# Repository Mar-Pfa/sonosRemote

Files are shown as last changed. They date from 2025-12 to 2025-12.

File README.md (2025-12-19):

# sonosRemote
simple hardware remote control for my sonos speaker

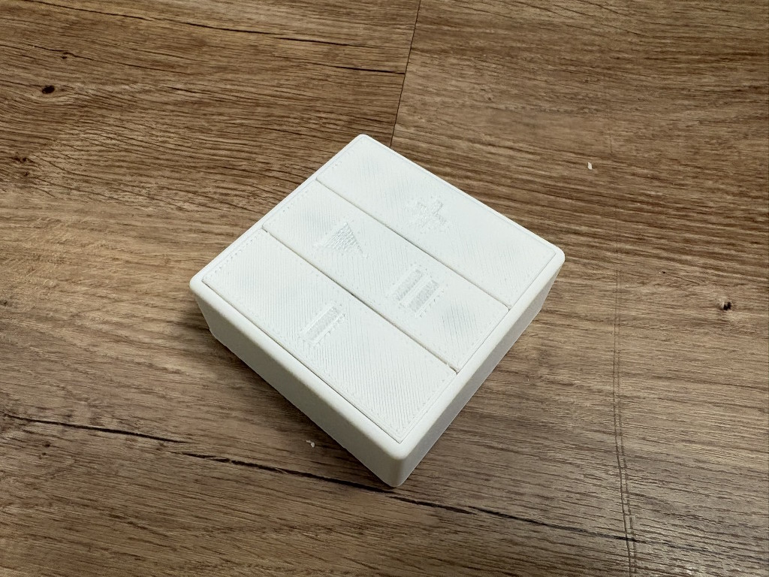
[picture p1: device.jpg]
device

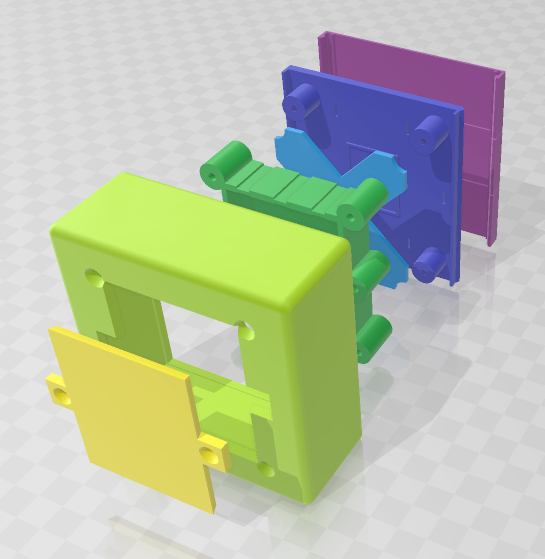
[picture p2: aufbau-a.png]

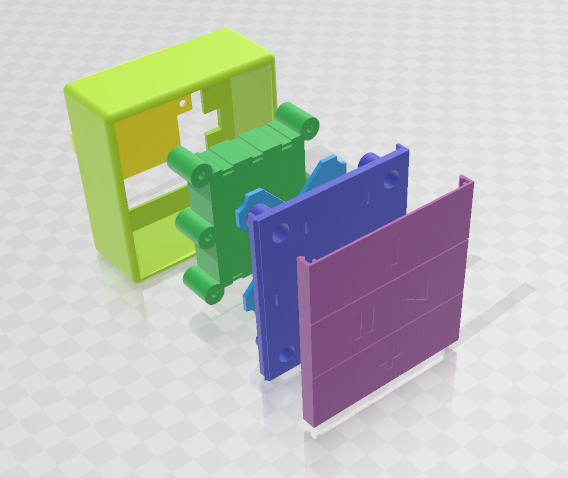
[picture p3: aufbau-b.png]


# ESP32 ⚙️ Funktionen

- **3 Taster** für Lauter, Play/Pause, Leiser
- **Deep Sleep** im Ruhezustand (<0.1 mA)
- **Wake-up per GPIO** (Tasterdruck auf Lauter)
- **60 Sekunden Aktiv-Zeit** vor erneutem Schlaf
- **WLAN-Verbindung** zu Sonos-Lautsprecher
- **mDNS-Unterstützung** (z. B. `http://sonosremote.local`)
- **Arduino OTA** für Over-the-Air-Updates

---

## 💡 LED Statusanzeige

Die eingebaute LED zeigt verschiedene Gerätezustände an:

| Zustand | LED-Muster | Bedeutung |
|---|---|---|
| Startphase | 0,1s an / 0,15s aus | WLAN-Verbindungsaufbau läuft |
| Tastendruck | 0,5s an | Bestätigung der Tasteneingabe |
| Aktiv-Wartemodus | 0,1s an / 0,4s aus | Gerät ist aktiv, wartet auf Befehle/OTA |
| Deep Sleep | LED aus | Gerät im Stromsparmodus |

Die LED-Zeiten können über Konstanten in `sonos.ino` angepasst werden:
```cpp
#define LED_STARTUP_ON_MS   100  // LED an während Start
#define LED_STARTUP_OFF_MS  150  // LED aus während Start
#define LED_FEEDBACK_MS     500  // Tastendruckbestätigung
#define LED_IDLE_ON_MS      100  // LED an im Wartezustand
#define LED_IDLE_OFF_MS     400  // LED aus im Wartezustand
```

---

## 🔧 Hardwareit Deep Sleep, OTA & mDNS

## 🎯 Ziel

Ein ESP32-Sketch, der sich per WLAN verbindet, drei Taster ausliest und bei Tastendruck einen definierten Sonos-Lautsprecher steuert.  
Das System ist stromsparend durch Deep Sleep, unterstützt mDNS und Arduino OTA.

---

## 🔧 Benötigte Komponenten

| Komponente | Bild
|---|--- |
| ESP32C3 Supermini |
| Akku - 3× 1.2 V NiMH (3.6 V gesamt) |
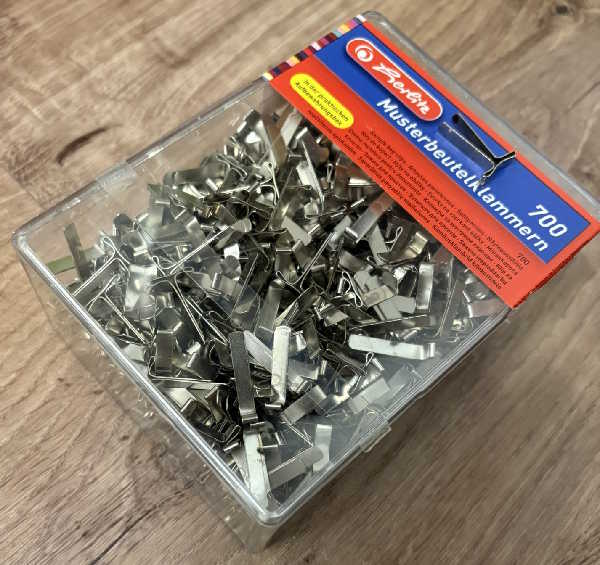
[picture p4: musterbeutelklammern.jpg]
| Musterbeutelklammern für die elektrischen Kontakte an der Batterie | 
| Ein paar kleine Kabel |
| etwas Alufolie als Kontaktschalter auf der Unterseite der Knöpfe |
| Sonos Lautsprecher - WLAN-fähig, im gleichen Netz |

---

## 🧱 Gehäuse & 3D-Dateien

Im Ordner `3d/` befinden sich **alle nötigen 3D-Dateien** für das Gehäuse:

- Die Datei `remote.3mf` enthält **alle Komponenten** zusammen; **alle "weißen" Objekte müssen subtrahiert werden**, bevor die Teile zusammengesetzt bzw. gedruckt werden.
- Zusätzlich gibt es die Einzelteile als `*.stl`-Dateien (z. B. `Baseplate.3mf`, `BatteryHolder.3mf`, `Buttons.3mf`).

> **Tipp:** Öffne `remote.3mf` in deinem 3D-Programm, führe die Subtraktion der weißen Objekte aus und exportiere bei Bedarf einzelne STL-Dateien für den Druck. 🔧

---

## ⚠️ WLAN-Einstellungen

Die **WLAN-Einstellungen (SSID, Passwort, evtl. statische IP)** befinden sich in `sonos/settings.h`. **Ändere dort die Werte vor dem ersten Flashen des Geräts.**

---

## 💻 Bibliotheken

- `WiFi.h`
- `SonosUPnP.h` ([javos65/Sonos-ESP32](https://github.com/javos65/Sonos-ESP32))
- `ArduinoOTA.h`
- `ESPmDNS.h`

---

## 🔋 Energieverbrauch & Laufzeit

| Zustand | Strom | Dauer/Tag | Verbrauch |
|---|---|---|---|
| Deep Sleep | 0.08 mA | 23 h 50 min | 2 mAh |
| Aktiv (WLAN, OTA-fähig) | 90 mA | 10 s × 100 | 25 mAh |
| **Gesamt** | | | **≈ 27 mAh/Tag** |

Mit 1200 mAh Akku: **ca. 44 Tage Laufzeit** bei 100 Betätigungen/Tag  
→ bei geringerer Nutzung: **mehrere Monate Laufzeit**.

---

## 🧠 Ablauf

1. **Deep Sleep:** ESP32 schläft mit nur RTC aktiv (0.05–0.1 mA).  
2. **Tastendruck:** weckt ESP32 (Wake-on-GPIO).  
3. **WLAN-Verbindung:** Aufbau (~1–2 s).  
4. **Sonos-Befehl:** Lauter, Leiser oder Play/Pause.  
5. **OTA/mDNS aktiv:** 60 s lang erreichbar.  
6. **Automatisch zurück in Deep Sleep.**

---

## 💡 Tipps

- OTA funktioniert **nur während der Aktivzeit (60 s)**.  
  → Taste drücken, dann OTA-Upload starten.  
- mDNS erlaubt Zugriff via `http://sonosremote.local` oder Ping.  
- Aktivzeit anpassen über:
  ```cpp
  const uint64_t AUTO_SLEEP_AFTER_MS = 60000; // 10 Sekunden
  ```

---

## ✅ Vorteile

- Extrem stromsparend
- schnelle Reaktion (<2 s)
- OTA & mDNS ohne Kabel
- Ideal für Akkubetrieb

---

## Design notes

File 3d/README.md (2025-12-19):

# Infos zum Druck

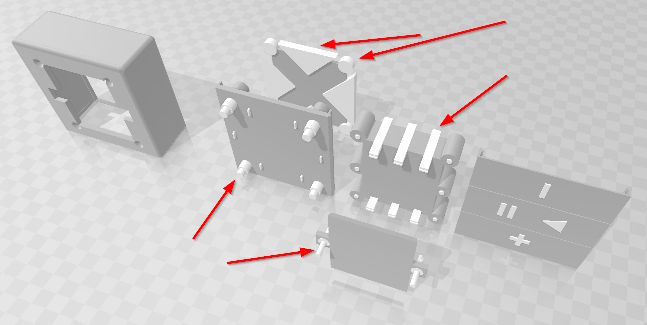
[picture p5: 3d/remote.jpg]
remote


In diesem Ordner findest du alle 3D-Dateien für das Gehäuse:

- **`remote.3mf`** — enthält alle Komponenten; das Modell wurde mit Microsoft 3D Builder erstellt. **Wichtiger Hinweis:** Alle **"weißen" Objekte** müssen vor dem Export bzw. Druck **subtrahiert** (Boolean/Difference) werden, da sie als Platzhalter/Schnitt-Objekte dienen.
- **Einzelteile / STLs** — zusätzlich liegen die Einzeldateien als STL-Exporte vor (z. B. `Baseplate.stl`, `BatteryDeckel.stl`, `Buttons.stl`, `Abdeckplatte.stl`) und können verwendet werden, wenn keine weiteren Anpassungen nötig sind.

### 3D-Druck

Für meine Fernbedienung habe ich alle Teile mit folgenden Settings gedruckt: 
- Schichthöhe: **0.2 mm** 
- Infill: **25 %**

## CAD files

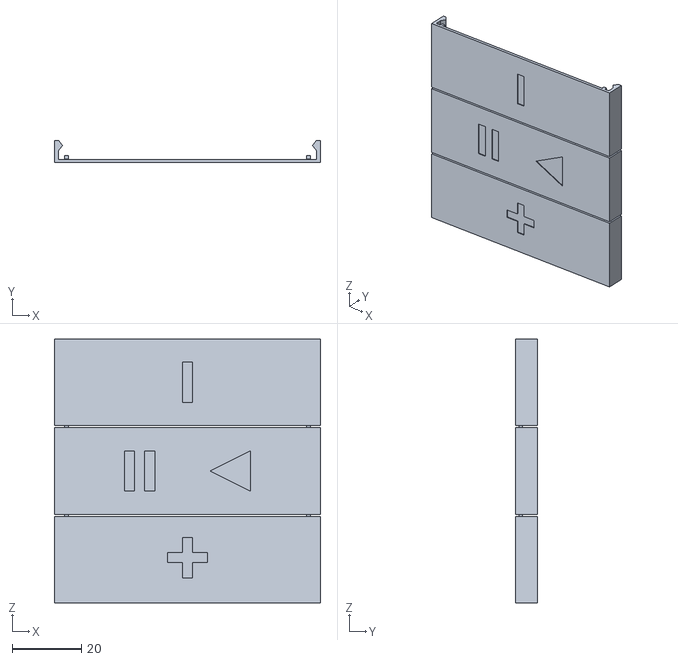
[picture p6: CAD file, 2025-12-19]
3d/Buttons.stl
77.0 x 6.50 x 76.4

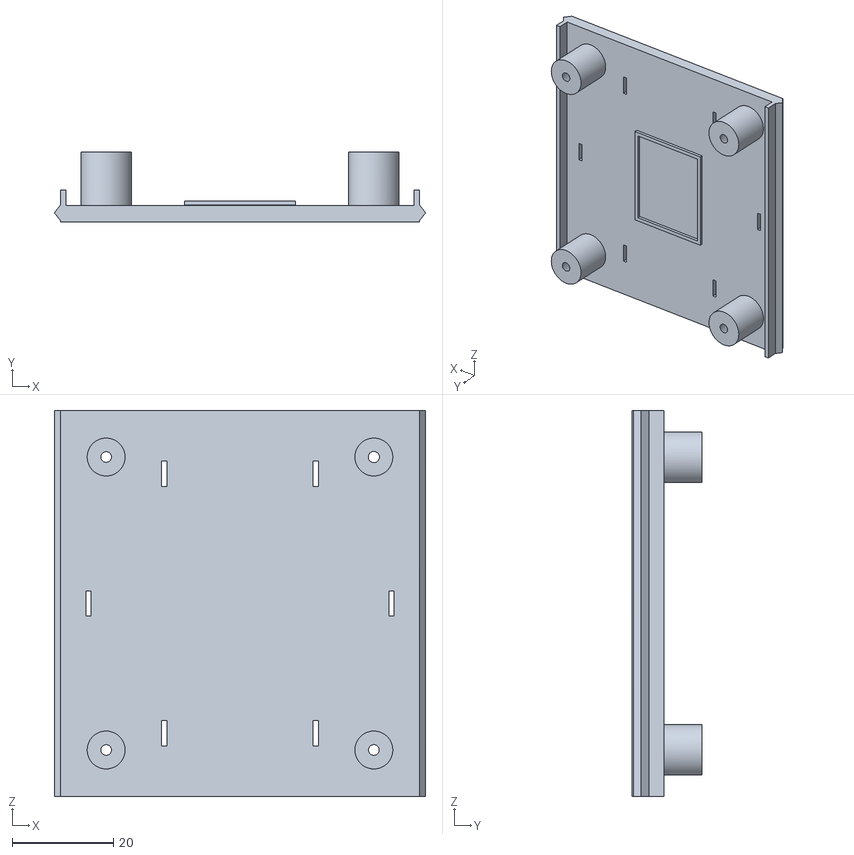
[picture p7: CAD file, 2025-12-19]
3d/Baseplate.stl
73.5 x 13.8 x 76.4

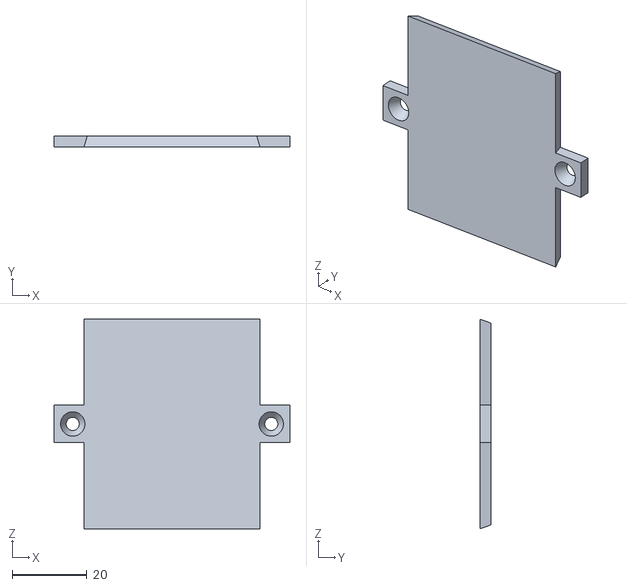
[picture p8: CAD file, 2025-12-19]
3d/BatterieDeckel.stl
63.0 x 3.00 x 56.0

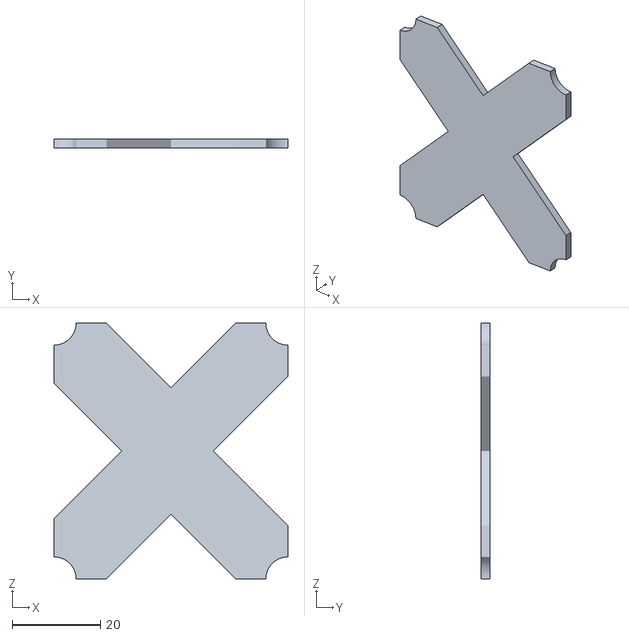
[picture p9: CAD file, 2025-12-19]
3d/Abdeckplatte.stl
53.0 x 2.00 x 58.0

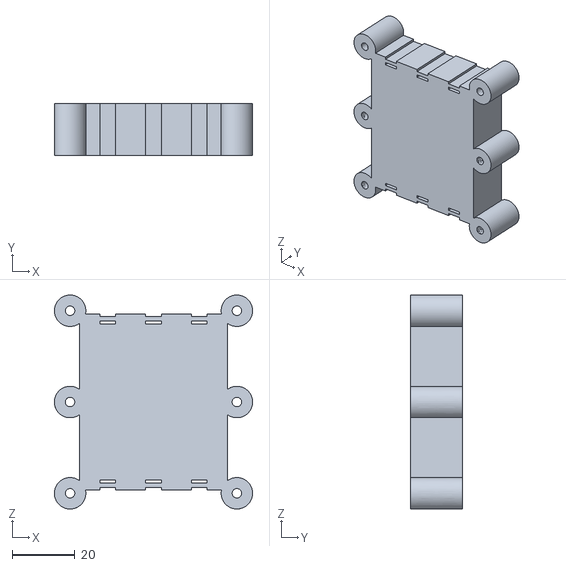
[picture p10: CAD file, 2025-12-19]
3d/batterieGehäuse.stl
63.0 x 16.5 x 68.0

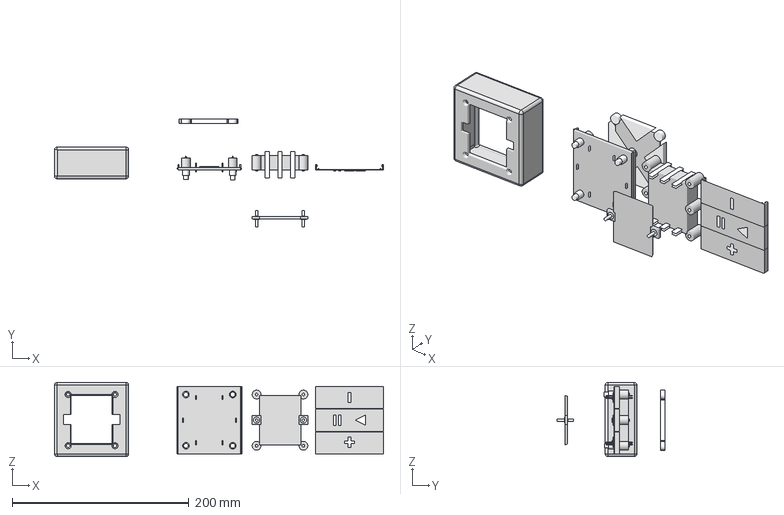
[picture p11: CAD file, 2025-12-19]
3d/remote.3mf
372.5 x 122.5 x 84.0 mm

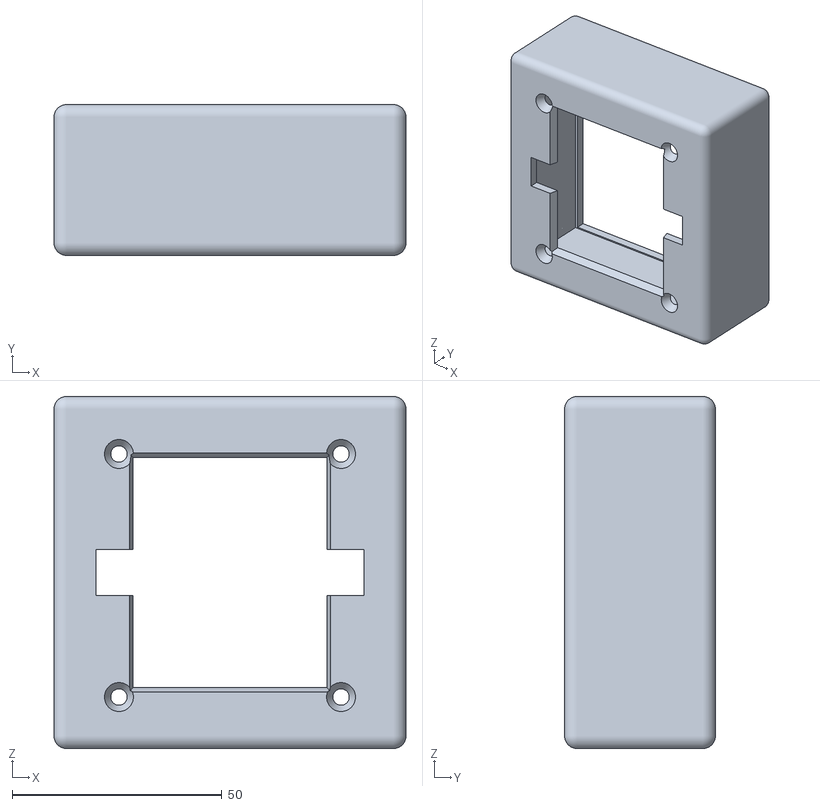
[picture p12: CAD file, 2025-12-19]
3d/Gehäuse.stl
84.0 x 36.0 x 84.0

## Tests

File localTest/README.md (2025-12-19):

# Sonos Web Remote

Eine einfache Weboberfläche zur Steuerung eines Sonos-Lautsprechers.

## Installation

1. Node.js installieren (v14 oder höher)
2. In das `web`-Verzeichnis wechseln:
   ```bash
   cd web
   ```
3. Dependencies installieren:
   ```bash
   npm install
   ```
4. Server starten:
   ```bash
   npm start
   ```
5. Im Browser öffnen: http://localhost:3000

## Funktionen

- Play/Pause Toggle
- Lautstärke erhöhen (+5)
- Lautstärke verringern (-5)

## Technische Details

- Express.js Server
- Direkter UPnP/SOAP-Zugriff auf Sonos
- Responsives Web-Interface
- Fehlerbehandlung mit visueller Rückmeldung

## Konfiguration

Die Sonos-IP-Adresse kann in `server.js` angepasst werden:

```js
const SONOS_IP = '192.168.2.228';  // IP des Sonos-Lautsprechers
```

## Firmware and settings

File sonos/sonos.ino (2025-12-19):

#include <WiFi.h>
#include <ArduinoOTA.h>
#include <ESPmDNS.h>
#include "esp_sleep.h"
#include "SonosUPnP.h"
#include "settings.h"

// ===== WLAN & Sonos =====
IPAddress SONOS_IP(192,168,2,228);
WiFiClient wifiClient;
SonosUPnP sonos(wifiClient);

// ===== mDNS & OTA =====
const char* HOSTNAME = "sonosremote";

// ===== Button Pins =====
#define BTN_DOWN 3
#define BTN_PLAY 4
#define BTN_UP   5

// ===== LED =====
#define LED_PIN 2 // onboard LED (change if different)

// LED state/timers
unsigned long ledFeedbackUntil = 0; // millis until which feedback LED stays on
unsigned long ledBlinkNext = 0;     // next toggle time for idle blink
bool ledBlinkOn = false;

// ===== LED Timing Constants (ms) =====
#define LED_STARTUP_ON_MS   100
#define LED_STARTUP_OFF_MS  150
#define LED_FEEDBACK_MS     500
#define LED_IDLE_ON_MS      100
#define LED_IDLE_OFF_MS     400
#define WIFI_CONNECT_TIMEOUT_MS 7000

// ===== Sleep Settings =====
const uint64_t AUTO_SLEEP_AFTER_MS = 60000;   // 30 Sekunden aktiv
RTC_DATA_ATTR int wakePin = -1;
unsigned long lastAction = 0;
bool actionDone = false;

// ===== Lautstärke Schrittweite =====
const int VOL_STEP = 5;

void setupButtons() {
  // Buttons are wired to GND; use internal pull-ups.
  pinMode(BTN_DOWN, INPUT_PULLUP);
  pinMode(BTN_PLAY, INPUT_PULLUP);
  pinMode(BTN_UP, INPUT_PULLUP);
  pinMode(LED_PIN, OUTPUT);
  digitalWrite(LED_PIN, LOW);
}

// --- Deep Sleep Setup ---
void goToSleep() {
  Serial.println("Gehe in Deep Sleep...");

  // Wakeup sources intentionally left default for widest compatibility

  // Ensure LED off before sleeping
  digitalWrite(LED_PIN, LOW);

  // Configure wakeup: use EXT0 on the volume-up button (BTN_UP).
  // Buttons are wired to GND, so we wake on LOW (pressed).
  // Note: EXT0 supports only a single RTC-capable GPIO. If this pin is not RTC-capable,
  // move the wake button to a supported pin or use an alternate wiring.
  // esp_deep_sleep_enable_gpio_wakeup((gpio_num_t)BTN_UP, 0);  
  esp_deep_sleep_enable_gpio_wakeup(1ULL << BTN_UP, ESP_GPIO_WAKEUP_GPIO_LOW);
  
  Serial.printf("Configured EXT0 wake on pin %d (level LOW)\n", BTN_UP);

  WiFi.disconnect(true);
  WiFi.mode(WIFI_OFF);

  delay(100);
  esp_deep_sleep_start();
}

// --- OTA Setup ---
void setupOTA() {
  ArduinoOTA.setHostname(HOSTNAME);
  ArduinoOTA
    .onStart([]() { Serial.println("OTA Start"); })
    .onEnd([]() { Serial.println("\nOTA Ende"); })
    .onProgress([](unsigned int progress, unsigned int total) {
      Serial.printf("Fortschritt: %u%%\r", (progress / (total / 100)));
    })
    .onError([](ota_error_t error) {
      Serial.printf("Fehler[%u]: ", error);
    });
  ArduinoOTA.begin();
  Serial.println("OTA bereit.");
}

// --- mDNS Setup ---
void setupMDNS() {
  if (!MDNS.begin(HOSTNAME)) {
    Serial.println("Fehler bei mDNS Start");
    return;
  }
  Serial.printf("mDNS aktiv: http://%s.local\n", HOSTNAME);
}

void setup() {
  Serial.begin(115200);
  delay(50);

  esp_sleep_wakeup_cause_t wakeup_reason = esp_sleep_get_wakeup_cause();

  setupButtons();

  if (wakeup_reason == ESP_SLEEP_WAKEUP_EXT0 ||
      wakeup_reason == ESP_SLEEP_WAKEUP_EXT1) {
    if (!digitalRead(BTN_DOWN)) wakePin = BTN_DOWN;
    else if (!digitalRead(BTN_UP)) wakePin = BTN_UP;
    else if (!digitalRead(BTN_PLAY)) wakePin = BTN_PLAY;
  } else {
    wakePin = -1;
  }

  Serial.printf("Wake reason: %d, pin: %d\n", wakeup_reason, wakePin);

  WiFi.mode(WIFI_STA);
  WiFi.setSleep(false);
  WiFi.begin(ssid, password);

  Serial.print("Verbinde WLAN");
  unsigned long start = millis();
  // Startup flashing until WiFi connects: LED_STARTUP_ON_MS on, LED_STARTUP_OFF_MS off
  while (WiFi.status() != WL_CONNECTED && millis() - start < WIFI_CONNECT_TIMEOUT_MS) {
    digitalWrite(LED_PIN, HIGH);
    delay(LED_STARTUP_ON_MS);
    digitalWrite(LED_PIN, LOW);
    delay(LED_STARTUP_OFF_MS);
    Serial.print(".");
  }
  Serial.println();
  if (WiFi.status() == WL_CONNECTED) Serial.println(WiFi.localIP());
  else Serial.println("WLAN nicht verbunden");

  setupMDNS();
  setupOTA();

  // Aktion ausführen, falls durch Taste geweckt
  if (wakePin == BTN_DOWN) {
    Serial.println("→ Leiser");
    uint8_t cur = sonos.getVolume(SONOS_IP);
    int v = cur - VOL_STEP;
    if (v < 0) v = 0;
    Serial.printf("Calling Sonos %u.%u.%u.%u:%d SetVolume %d\n", SONOS_IP[0], SONOS_IP[1], SONOS_IP[2], SONOS_IP[3], UPNP_PORT, v);
    sonos.setVolume(SONOS_IP, (uint8_t)v);
    actionDone = true;
  } else if (wakePin == BTN_UP) {
    Serial.println("→ Lauter");
    uint8_t cur = sonos.getVolume(SONOS_IP);
    int v = cur + VOL_STEP;
    if (v > 100) v = 100;
    Serial.printf("Calling Sonos %u.%u.%u.%u:%d SetVolume %d\n", SONOS_IP[0], SONOS_IP[1], SONOS_IP[2], SONOS_IP[3], UPNP_PORT, v);
    sonos.setVolume(SONOS_IP, (uint8_t)v);
    actionDone = true;
  } else if (wakePin == BTN_PLAY) {
    Serial.println("→ Play/Pause");
    Serial.printf("Calling Sonos %u.%u.%u.%u:%d TogglePlayPause\n", SONOS_IP[0], SONOS_IP[1], SONOS_IP[2], SONOS_IP[3], UPNP_PORT);
    sonos.togglePause(SONOS_IP);
    actionDone = true;
  }

  // Give brief feedback LED when waking from standby + action
  if (actionDone) {
    ledFeedbackUntil = millis() + LED_FEEDBACK_MS; // feedback
    digitalWrite(LED_PIN, HIGH);
  }

  lastAction = millis();
}

void loop() {
  ArduinoOTA.handle();  // OTA im Wachzustand aktiv

  // Wenn Taste gedrückt → Aktion + Reset Timer
  bool downPressed = !digitalRead(BTN_DOWN);
  bool upPressed = !digitalRead(BTN_UP);
  bool playPressed = !digitalRead(BTN_PLAY);

  if (downPressed || upPressed || playPressed) {
    // Debug-Ausgabe welche Taste erkannt wurde
    Serial.print("Button pressed:");
    if (downPressed) Serial.print(" DOWN");
    if (upPressed) Serial.print(" UP");
    if (playPressed) Serial.print(" PLAY");
    Serial.println();

    lastAction = millis();

    // sofort sichtbares kurzes Feedback
    digitalWrite(LED_PIN, HIGH);
    delay(80);
    digitalWrite(LED_PIN, LOW);

    if (downPressed) {
      Serial.println("-> setVolume down");
      uint8_t cur = sonos.getVolume(SONOS_IP);
      Serial.printf(" cur=%u\n", cur);
      int v = cur - VOL_STEP; if (v < 0) v = 0;
      Serial.printf("Calling Sonos %u.%u.%u.%u:%d SetVolume %d\n", SONOS_IP[0], SONOS_IP[1], SONOS_IP[2], SONOS_IP[3], UPNP_PORT, v);
      sonos.setVolume(SONOS_IP, (uint8_t)v);
      Serial.println(" done");
    }
    if (upPressed) {
      Serial.println("-> setVolume up");
      uint8_t cur = sonos.getVolume(SONOS_IP);
      Serial.printf(" cur=%u\n", cur);
      int v = cur + VOL_STEP; if (v > 100) v = 100;
      Serial.printf("Calling Sonos %u.%u.%u.%u:%d SetVolume %d\n", SONOS_IP[0], SONOS_IP[1], SONOS_IP[2], SONOS_IP[3], UPNP_PORT, v);
      sonos.setVolume(SONOS_IP, (uint8_t)v);
      Serial.println(" done");
    }
    if (playPressed) {
      Serial.println("-> togglePause");
      Serial.printf("Calling Sonos %u.%u.%u.%u:%d TogglePlayPause\n", SONOS_IP[0], SONOS_IP[1], SONOS_IP[2], SONOS_IP[3], UPNP_PORT);
      sonos.togglePause(SONOS_IP);
      Serial.println(" done");
    }

    // Start feedback LED for configured duration
    ledFeedbackUntil = millis() + LED_FEEDBACK_MS;
    digitalWrite(LED_PIN, HIGH);
    delay(250); // Entprellen
  }

  unsigned long now = millis();

  // turn off feedback LED when time expired
  if (ledFeedbackUntil && now >= ledFeedbackUntil) {
    ledFeedbackUntil = 0;
    digitalWrite(LED_PIN, LOW);
  }

  // While active and waiting for going to standby show idle blink pattern:
  // 0.1s on, 0.4s off
  if (now - lastAction > 1000 && now - lastAction < AUTO_SLEEP_AFTER_MS) {
    if (now >= ledBlinkNext) {
      if (!ledBlinkOn) {
        // turn on for LED_IDLE_ON_MS
        digitalWrite(LED_PIN, HIGH);
        ledBlinkOn = true;
        ledBlinkNext = now + LED_IDLE_ON_MS;
      } else {
        // turn off for LED_IDLE_OFF_MS
        digitalWrite(LED_PIN, LOW);
        ledBlinkOn = false;
        ledBlinkNext = now + LED_IDLE_OFF_MS;
      }
    }
  } else {
    // ensure idle blink state reset when recent activity or sleeping
    ledBlinkOn = false;
    ledBlinkNext = now;
  }

  // Nach AUTO_SLEEP_AFTER_MS ohne Aktion → Sleep (ensure LED off)
  if (now - lastAction > AUTO_SLEEP_AFTER_MS) {
    digitalWrite(LED_PIN, LOW);
    goToSleep();
  }

  delay(10);
}

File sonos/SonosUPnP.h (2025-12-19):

/************************************************************************/
/* Sonos UPnP, an UPnP based read/write remote control library, v2.1.   */
/*                                                                      */
/* This library is free software: you can redistribute it and/or modify */
/* it under the terms of the GNU General Public License as published by */
/* the Free Software Foundation, either version 3 of the License, or    */
/* (at your option) any later version.                                  */
/*                                                                      */
/* This library is distributed in the hope that it will be useful, but  */
/* WITHOUT ANY WARRANTY; without even the implied warranty of           */
/* MERCHANTABILITY or FITNESS FOR A PARTICULAR PURPOSE. See the GNU     */
/* General Public License for more details.                             */
/*                                                                      */
/* You should have received a copy of the GNU General Public License    */
/* along with this library. If not, see <http://www.gnu.org/licenses/>. */
/*                                                                      */
/* Written by Thomas Mittet (code@lookout.no) January 2015.             */
/*                                                                      */
/* Modified for use with Wifi.h or WifiNINA.h for wireless Networking   */
/* Added uPnP Network Scan function  Jay Vox 2020                       */
/************************************************************************/

#ifndef SonosUPnP_h
   #define SonosUPnP_h

//#define SONOS_WRITE_ONLY_MODE

#include <Arduino.h>
//#if (defined(__AVR__))
//  #include <avr/pgmspace.h>
//#else
//  #include <pgmspace.h>
//#endif

#ifndef SONOS_WRITE_ONLY_MODE
#include <MicroXPath_P.h>
#endif
#if defined(ARDUINO_ARCH_ESP32) || defined(ESP32)
#include <WiFi.h>
#else
#include <WiFiNINA.h>  // JV : Wireless Mkr1010
#endif
#include <WiFiUdp.h>   // JV : UDP service

// HTTP:
#define HTTP_VERSION " HTTP/1.1\n"
#define HEADER_HOST "Host: %d.%d.%d.%d:%d\n"
#define HEADER_CONTENT_TYPE "Content-Type: text/xml; charset=\"utf-8\"\n"
#define HEADER_CONTENT_LENGTH "Content-Length: %d\n"
#define HEADER_SOAP_ACTION "SOAPAction: \"urn:"
#define HEADER_SOAP_ACTION_END "\"\n"
#define HEADER_CONNECTION "Connection: close\n"

// SOAP tag data:
#define SOAP_ENVELOPE_START "<s:Envelope xmlns:s=\"http://schemas.xmlsoap.org/soap/envelope/\" s:encodingStyle=\"http://schemas.xmlsoap.org/soap/encoding/\">"
#define SOAP_ENVELOPE_END "</s:Envelope>"
#define SOAP_BODY_START "<s:Body>"
#define SOAP_BODY_END "</s:Body>"
#define SOAP_TAG_START "<%s>"
#define SOAP_TAG_END "</%s>"
#define SOAP_TAG_LEN 5
#define SOAP_TAG_ENVELOPE "s:Envelope"
#define SOAP_TAG_BODY "s:Body"

// UPnP config:
#define UPNP_PORT 1400
#define UPNP_MULTICAST_IP (byte[]) {239,255,255,250}
#define UPNP_MULTICAST_PORT 1900
#define UPNP_MULTICAST_TIMEOUT_S 2
#define UPNP_RESPONSE_TIMEOUT_MS 3000
#define UPNP_DEVICE_SCAN "M-SEARCH * HTTP/1.1\nHOST: 239.255.255.250:1900\nMAN: \"ssdp:discover\"\nMX: 2\nST: urn:schemas-upnp-org:device:ZonePlayer:1\n\0"

// UPnP tag data:
#define SOAP_ACTION_START_TAG_START "<u:"
#define SOAP_ACTION_START_TAG_NS " xmlns:u=\"urn:"
#define SOAP_ACTION_START_TAG_END "\">"
#define SOAP_ACTION_END_TAG_START "</u:"
#define SOAP_ACTION_END_TAG_END ">"
#define SOAP_ACTION_TAG_LEN 24

// UPnP service data:
#define UPNP_URN_SCHEMA "schemas-upnp-org:service:"
#define UPNP_AV_TRANSPORT 1
#define UPNP_AV_TRANSPORT_SERVICE "AVTransport:1"
#define UPNP_AV_TRANSPORT_ENDPOINT "/MediaRenderer/AVTransport/Control"
#define UPNP_RENDERING_CONTROL 2
#define UPNP_RENDERING_CONTROL_SERVICE "RenderingControl:1"
#define UPNP_RENDERING_CONTROL_ENDPOINT "/MediaRenderer/RenderingControl/Control"
#define UPNP_DEVICE_PROPERTIES 3
#define UPNP_DEVICE_PROPERTIES_SERVICE "DeviceProperties:1"
#define UPNP_DEVICE_PROPERTIES_ENDPOINT "/DeviceProperties/Control"


#define SONOS_TAG_GET_ZONE_ATTR "GetZoneAttributes"
#define SONOS_TAG_GET_ZONE_ATTR_RESPONSE "u:GetZoneAttributesResponse"
#define SONOS_TAG_ZONENAME "CurrentZoneName"
#define SONOS_TAG_GET_ZONE_INFO "GetZoneInfo"
#define SONOS_TAG_GET_ZONE_INFO_RESPONSE "u:GetZoneInfoResponse"
#define SONOS_TAG_SERIAL "ExtraInfo"

#define SONOS_GET_ZPSUPPORTINFO "ZPSupportInfo"
#define SONOS_GET_ZPINFO "ZPInfo"
#define SONOS_GET_ZPZONE "ZoneName"
#define SONOS_GET_ZPLOCALUID "LocalUID"
#define SONOS_GET_ZPSERIAL "SerialNumber"
#define SONOS_GET_ZPSERIESID "SeriesID"

// Sonos speaker state control:
/*
<u:Play>
  <InstanceID>0</InstanceID>
  <Speed>1</Speed>
</u:Play>
<u:Seek>
  <InstanceID>0</InstanceID>
  <Unit>REL_TIME</Unit>
  <Target>0:01:02</Target>
</u:Seek>
*/
#define SONOS_TAG_PLAY "Play"
#define SONOS_SOURCE_RINCON_TEMPLATE "RINCON_%s0%d%s"
#define SONOS_TAG_SPEED "Speed"
#define SONOS_TAG_STOP "Stop"
#define SONOS_TAG_PAUSE "Pause"
#define SONOS_TAG_PREVIOUS "Previous"
#define SONOS_TAG_NEXT "Next"
#define SONOS_DIRECTION_BACKWARD 0
#define SONOS_DIRECTION_FORWARD 1
#define SONOS_INSTANCE_ID_0_TAG "<InstanceID>0</InstanceID>"

#define SONOS_TAG_SEEK "Seek"
#define SONOS_TAG_TARGET "Target"
#define SONOS_SEEK_MODE_TAG_START "<Unit>"
#define SONOS_SEEK_MODE_TAG_END "</Unit>"
#define SONOS_SEEK_MODE_TRACK_NR "TRACK_NR"
#define SONOS_SEEK_MODE_REL_TIME "REL_TIME"
#define SONOS_TIME_FORMAT_TEMPLATE "%d:%02d:%02d"

#define SONOS_TAG_SET_AV_TRANSPORT_URI "SetAVTransportURI"
#define SONOS_TAG_CURRENT_URI "CurrentURI"
#define SONOS_URI_META_LIGHT_START "<CurrentURIMetaData>"
#define SONOS_URI_META_LIGHT_END "</CurrentURIMetaData>"
#define SONOS_RADIO_META_FULL_START "<CurrentURIMetaData>&lt;DIDL-Lite xmlns:dc=&quot;http://purl.org/dc/elements/1.1/&quot; xmlns:upnp=&quot;urn:schemas-upnp-org:metadata-1-0/upnp/&quot; xmlns:r=&quot;urn:schemas-rinconnetworks-com:metadata-1-0/&quot; xmlns=&quot;urn:schemas-upnp-org:metadata-1-0/DIDL-Lite/&quot;&gt;&lt;item id=&quot;R:0/0/46&quot; parentID=&quot;R:0/0&quot; restricted=&quot;true&quot;&gt;&lt;dc:title&gt;"
#define SONOS_RADIO_META_FULL_END "&lt;/dc:title&gt;&lt;upnp:class&gt;object.item.audioItem.audioBroadcast&lt;/upnp:class&gt;&lt;desc id=&quot;cdudn&quot; nameSpace=&quot;urn:schemas-rinconnetworks-com:metadata-1-0/&quot;&gt;SA_RINCON65031_&lt;/desc&gt;&lt;/item&gt;&lt;/DIDL-Lite&gt;</CurrentURIMetaData>"

#define SONOS_TAG_BECOME_COORDINATOR_OF_STANDALONE_GROUP "BecomeCoordinatorOfStandaloneGroup"

#define SONOS_TAG_SET_LED_STATE "SetLEDState"
#define SONOS_TAG_DESIRED_LED_STATE "DesiredLEDState"
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

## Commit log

2025-12-19 first commit with software, 3d-models and web-test-tool
    [Abdeckplatte.stl, Baseplate.stl, BatterieDeckel.stl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]
2025-12-19 add information for 3d-printing
